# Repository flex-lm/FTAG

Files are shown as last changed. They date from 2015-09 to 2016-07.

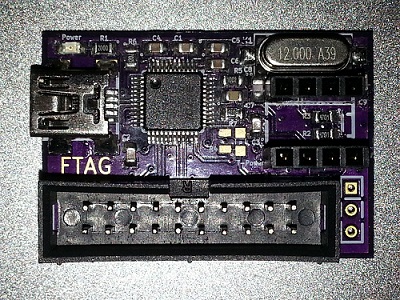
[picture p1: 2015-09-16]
pictures/board_component.jpg

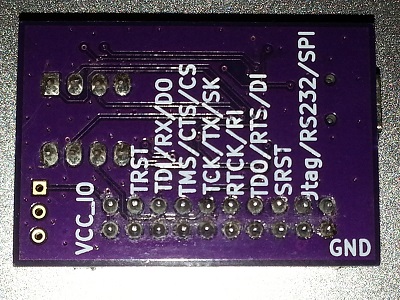
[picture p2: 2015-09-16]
pictures/board_solder.jpg

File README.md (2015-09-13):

# FTAG
This is a simple USB to Jtag, SPI and RS232 interface for experimental and research usage that's based around the FTDI FT232H.

Board top
Board solder

This circuit has experimental and dangerous features! Build at your own risk!

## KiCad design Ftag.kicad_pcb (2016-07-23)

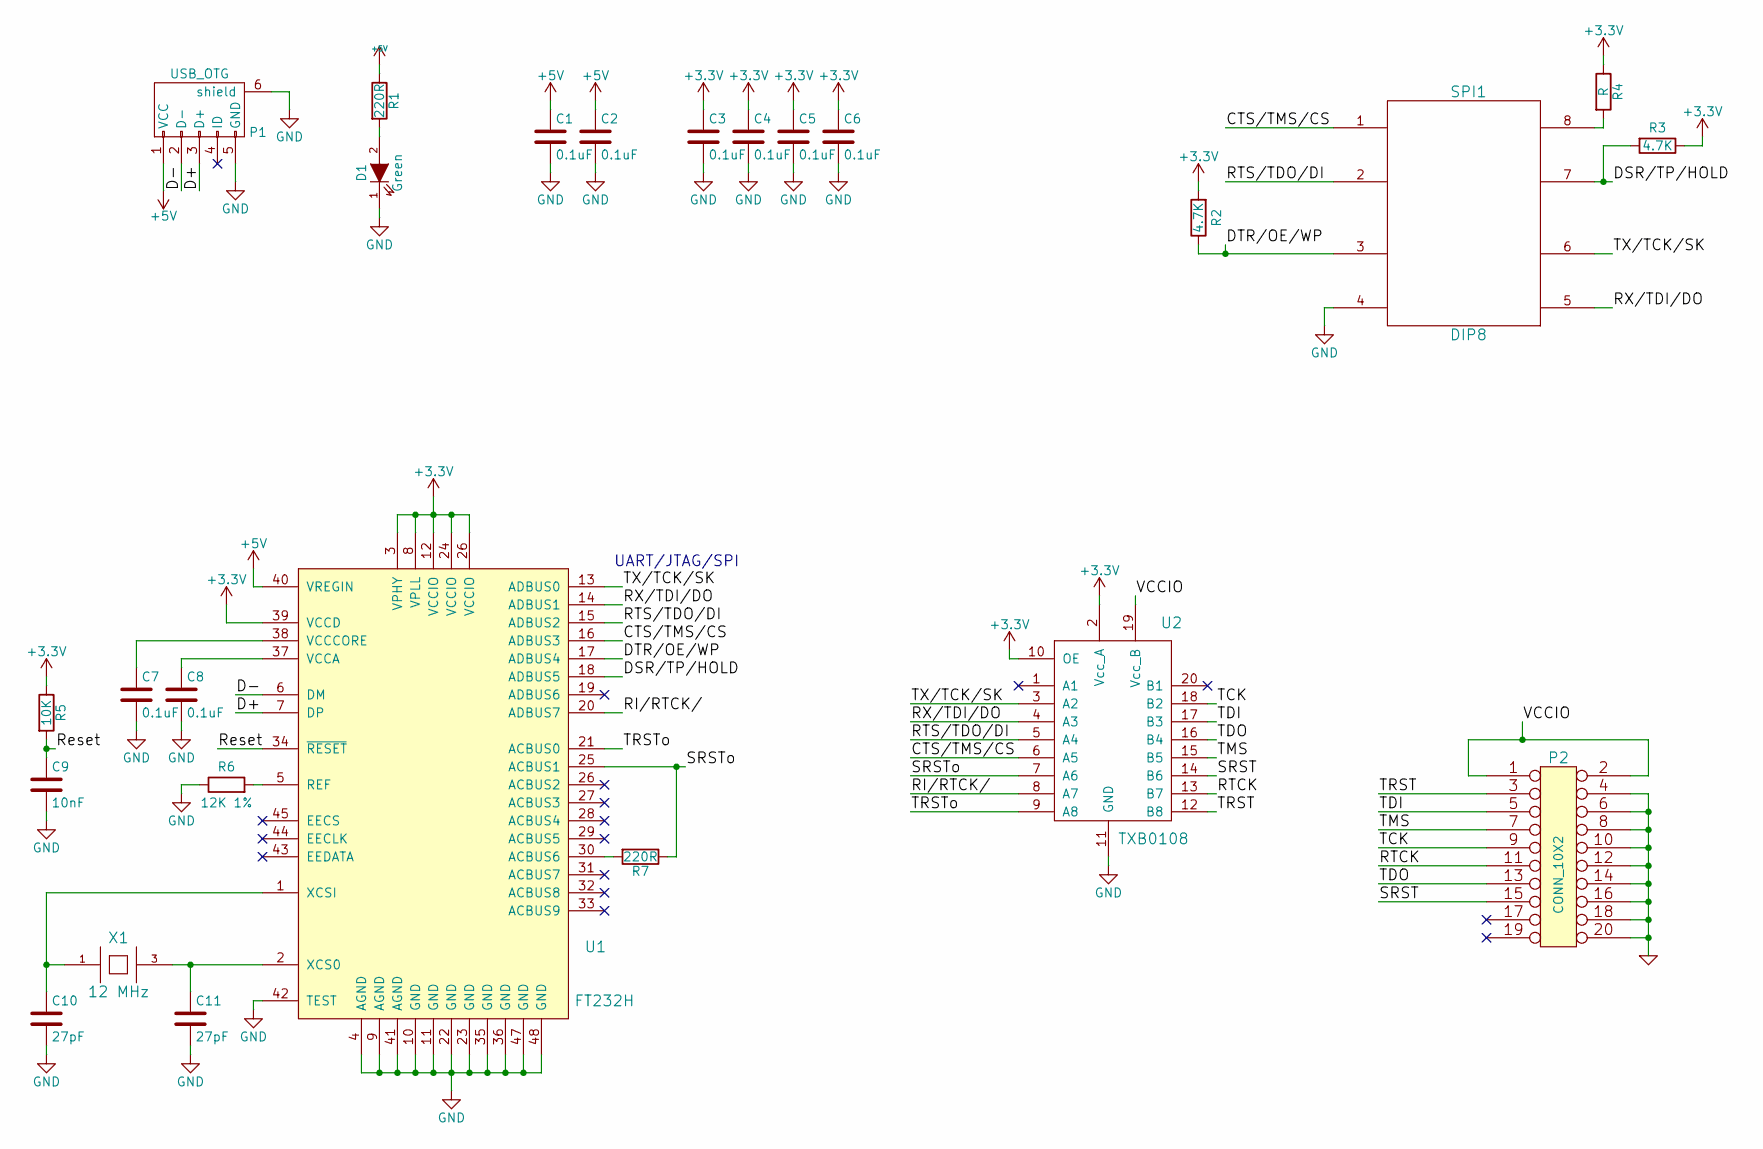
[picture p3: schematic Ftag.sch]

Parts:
C1, C2, C3, C4, C5, C6, C7, C8: 0.1uF; C_0603_HandSoldering
C9: 10nF; C_0603_HandSoldering
C10, C11: 27pF; C_0603_HandSoldering
D1: Green; LED_0805
P1: USB_OTG; USB_Micro-B
P2: CONN_10X2; IDC_Header_Straight_20pins
R1, R7: 220R; R_0603_HandSoldering
R2, R3: 4.7K; R_0603_HandSoldering
R4: R; R_0603_HandSoldering
R5: 10K; R_0603_HandSoldering
R6: 12K 1%; R_0603_HandSoldering
SPI1: DIP8; DIP-8_W7.62mm_LongPads
U1: FT232H; LQFP-48_7x7mm_Pitch0.5mm
U2: TXB0108; SSOP-20_4.4x6.5mm_Pitch0.65mm
X1: 12 MHz; Q_49U3HMS

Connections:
+3V3: C3.1, C4.1, C5.1, C6.1, R2.2, R3.1, R4.1, R5.1, U1.3 (VPHY), U1.8 (VPLL), U1.12 (VCCIO), U1.24 (VCCIO), U1.26 (ACBUS2), U1.39 (VCCD), U2.2 (Vcc_A), U2.10 (OE)
+5V: C1.1, C2.1, P1.1 (VCC), R1.1, U1.40 (VREGIN)
/CTS/TMS/CS: SPI1.1, U1.16 (ADBUS3), U2.6 (A5)
/D+: P1.3 (D+), U1.7 (DP)
/D-: P1.2 (D-), U1.6 (DM)
/DSR/TP/HOLD: R3.2, SPI1.7, U1.18 (ADBUS5)
/DTR/OE/WP: R2.1, SPI1.3, U1.17 (ADBUS4)
/RI/RTCK/: U1.20 (ADBUS7), U2.8 (A7)
/RTCK: P2.11, U2.13 (B7)
/RTS/TDO/DI: SPI1.2, U1.15 (ADBUS2), U2.5 (A4)
/RX/TDI/DO: SPI1.5, U1.14 (ADBUS1), U2.4 (A3)
/Reset: C9.1, R5.2, U1.34 (~RESET)
/SRST: P2.15, U2.14 (B6)
/SRSTo: R7.1, U1.25 (ACBUS1), U2.7 (A6)
/TCK: P2.9, U2.18 (B2)
/TDI: P2.5, U2.17 (B3)
/TDO: P2.13, U2.16 (B4)
/TMS: P2.7, U2.15 (B5)
/TRST: P2.3, U2.12 (B8)
/TRSTo: U1.21 (ACBUS0), U2.9 (A8)
/TX/TCK/SK: SPI1.6, U1.13 (ADBUS0), U2.3 (A2)
/VCCIO: P2.1, P2.2, U2.19 (Vcc_B)
GND: C1.2, C2.2, C3.2, C4.2, C5.2, C6.2, C7.2, C8.2, C9.2, C10.2, C11.2, D1.1 (K), P1.5 (GND), P1.6 (shield), P2.4, P2.6, P2.8, P2.10, P2.12, P2.14, P2.16, P2.18, P2.20, R6.1, SPI1.4, U1.4 (AGND), U1.9 (AGND), U1.10 (GND), U1.11 (GND), U1.22 (GND), U1.23 (GND), U1.35 (GND), U1.36 (GND), U1.41 (AGND), U1.42 (TEST), U1.47 (GND), U1.48 (GND), U2.11 (GND)
unnamed: C7.1, U1.38 (VCCCORE)
unnamed: C8.1, U1.37 (VCCA)
unnamed: C10.1, U1.1 (XCSI), X1.1
unnamed: C11.1, U1.2 (XCS0), X1.3
unnamed: D1.2 (A), R1.2
unnamed: R4.2, SPI1.8
unnamed: R6.2, U1.5 (REF)
unnamed: R7.2, U1.30 (ACBUS6)

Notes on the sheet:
UART/JTAG/SPI

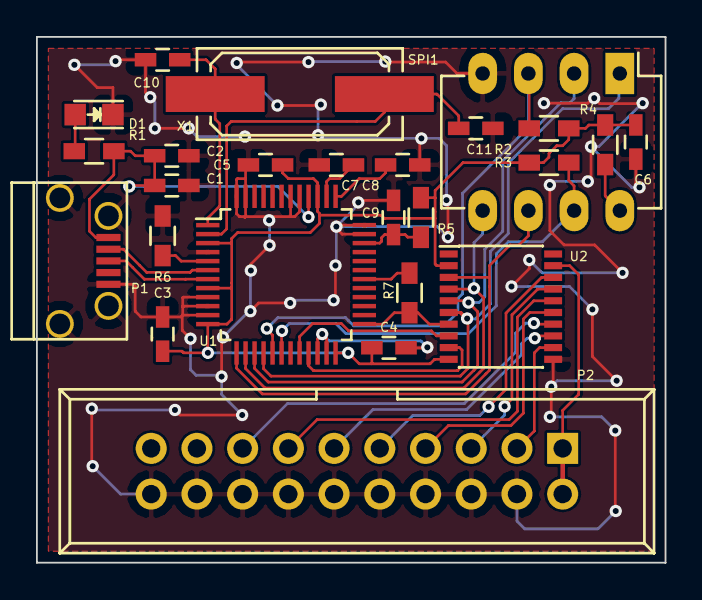
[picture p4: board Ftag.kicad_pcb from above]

Board: 2 copper layers, 34.9 x 29.2 mm, 25 parts (0 on the bottom side), 31 nets.

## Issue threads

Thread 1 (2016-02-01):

Lacks a voltage transceiver

flex-lm, 2016-02-01:
The latest version in master lacks a voltage transceiver, it can only be used with 3.3V targets.

flex-lm, 2016-07-24:
This has been addressed in the "development" branch.

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

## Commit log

2015-09-12 Lets hack embedded devices!
    [Ftag-B_Cu.gbl, Ftag-B_Mask.gbs, Ftag-B_SilkS.gbo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]
2015-09-13 Added note about experimental feature
    [Ftag.sch]
2015-09-13 Added pictures of the board
2015-11-27 removed experimental parts
    [Ftag.sch]
2015-12-07 Added output buffer
    Some things still have to be checked before adding part footprints
    [Ftag.sch]
2016-06-10 Changed buffer and updated schematic
2016-07-19 Assigned component footprints
    [Ftag.sch]
2016-07-20 Started board layout
    [Ftag.sch]
2016-07-20 Added some routing
    [Ftag.kicad_pcb, Ftag.sch]
2016-07-21 Finished preliminary layout
    [Ftag-B.Cu.gbr, Ftag-B.Mask.gbr, Ftag-B.SilkS.gbr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]
2016-07-22 Added via stitching
    [Ftag-B.Cu.gbr, Ftag-B.Mask.gbr, Ftag-B.SilkS.gbr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]
2016-07-22 Added silkscreen pinout
    [Ftag-B.Cu.gbr, Ftag-B.Mask.gbr, Ftag-B.SilkS.gbr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]
2016-07-23 Finished PCB layout
    [Ftag-B.Cu.gbr, Ftag-B.Mask.gbr, Ftag-B.SilkS.gbr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]
